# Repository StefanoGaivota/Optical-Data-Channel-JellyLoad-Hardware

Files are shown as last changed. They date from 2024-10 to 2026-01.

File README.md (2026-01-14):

Jelly Load is touted as one of the most inconvenient (but also most fun) ways of loading data into your 8 bit computer.<br>
The concept is the collaborative creation of Dave Curran (Tynemouth Software) and Rod Hull (The Future Was 8 bit).

Jelly-Load_Video-Excerpt

<br>
Data and clock signals are encoded into a video stream as a matrix of black or white areas.<br>
The receiving interface senses the optical channel bit state and converts the result into an 8 bit data word
for interpretation by the target computer upon receiving valid clock edge.

Take a look here:<br>
https://www.tfw8b.com/introducing-jelly-load/<br>
for a historical account.

The loader binaries for VIC20 can be found here:<br>
https://www.tfw8b.com/wp-content/uploads/2024/09/JellyLoad-VIC20-240908.zip<br>
(different ones depending upon your RAM configuration)

This repository is my own effort at creating a JellyLoad receive interface for Commodore computer user port.

It comprises two separate boards which connect to each other via a 14way IDC cable assembly along with associated opto-mechanical components.<br>
KiCAD source is available for schematic and PCB of each board.<br>
FreeCAD source is available for the mechanical elements (Optical Housing and Monitor Guide).<br>
Manufacturing data generated from these sources is detailed later in this document.<br><br>
<p><u><b>Printed Circuit Board parts</u></b></p><br>

* Optical Interface board:
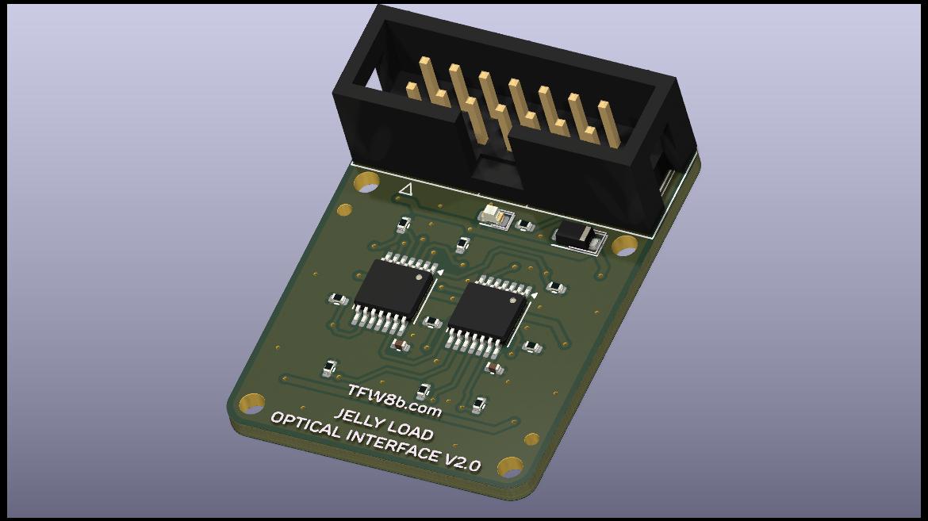
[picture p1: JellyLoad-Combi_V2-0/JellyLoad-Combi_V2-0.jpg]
Sensor-array-board

Phototransistors are arranged in the required matrix, photocurrent converted to voltage at input of Schmitt inverter. Inverter outputs are routed to 14 Way IDC.<br>
Clock signal is indicated by an LED for visual feedback of correct operation.<br>
Originally developed to use the OSRAM SFH3710 phototransistor, this seems to be superceded by the SFH3716 (as of December 2025).  Should be a drop-in replacement but YMMV.
<br><br>

* Target Interface board:
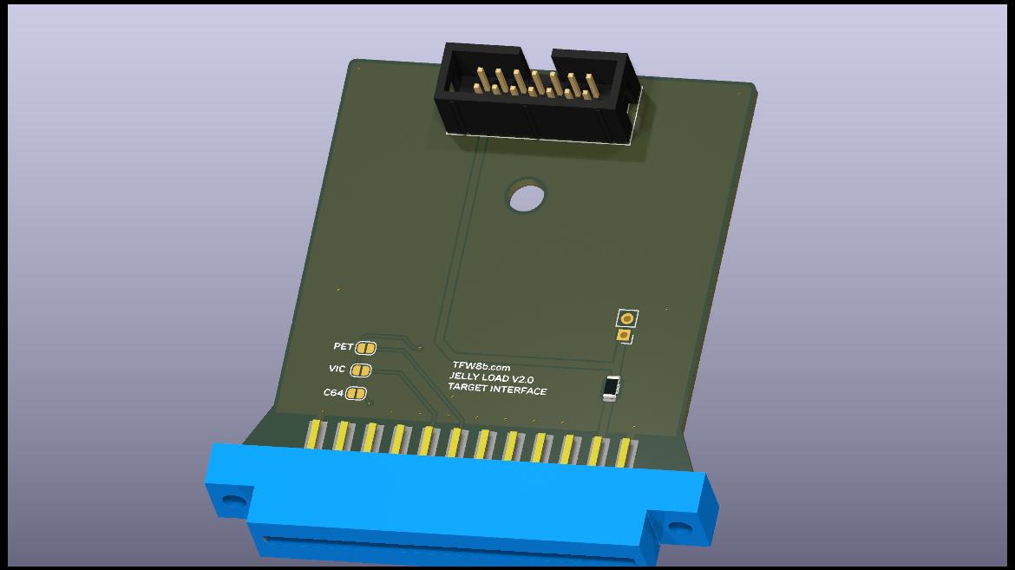
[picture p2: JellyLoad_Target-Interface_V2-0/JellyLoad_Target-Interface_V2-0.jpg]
Target-Interface-Board

Target interface connects the 14Way IDC pins and routes logic signals to target computer User Port connector.<br>
Solder blob config pads route the CLK signal to the user port pin required by the target computer.<br>
This differs between PET, VIC20 and C64. Blob your required option.<br>
Board profile is configured to fit inside a C64 cartridge case.<br>
Case mechanics are shown on layer User.Eco1.<br>
PDF of machining dimensions is made available for convenience.<br><br>
<br>
<p><u><b>Mechanical components</u></b></p><br>

* Optical Housing:
 
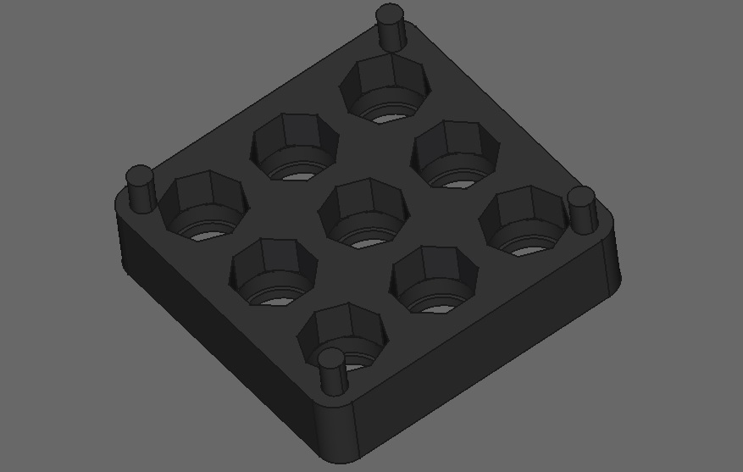
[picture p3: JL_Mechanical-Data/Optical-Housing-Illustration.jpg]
Optical-Housing


The Optical Interface board is fitted with this Optical Housing for the purpose of reducing ambient light interference and to help align with the optical channel.<br>
Optical aperture adaptors (glass spheres) are accommodated in this section to match the sensor aperture to the available width. A specification for suitable spheres is available in the mechanical data directory. Basically 6.0mm glass balls of good optical clarity.<br>
The graphical calculations shown here are based on a refractive index of 1.4.<br>

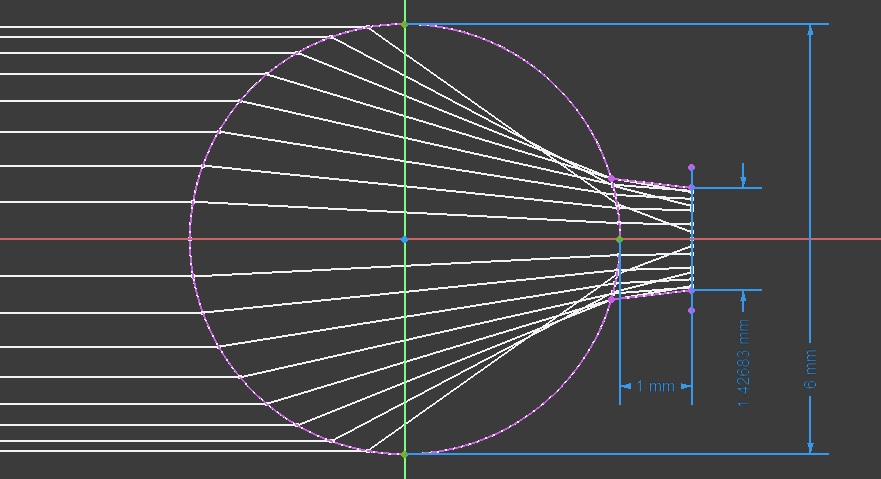
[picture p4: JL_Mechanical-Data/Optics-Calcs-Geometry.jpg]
Optics-Calculations

<br>
The sensor array will work adequately without the aperture adaptors but sensitivity will be reduced so you will need to use higher monitor brightness for reliable transmission. <br>
The housing can be secured to the sensor board with your adhesive of choice, (sticky tape, cyanoacrylate, blu-tack, toffee etc) or careful heat-staking of the retaining lugs.<br><br>

* Monitor Guide:

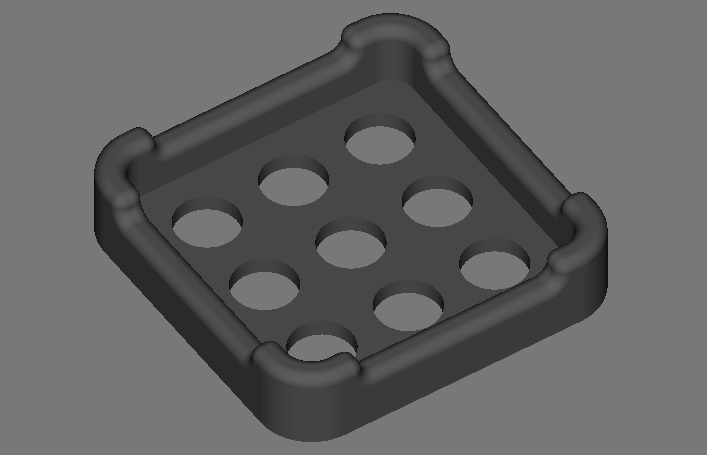
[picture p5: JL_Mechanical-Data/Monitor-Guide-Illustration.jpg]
Monitor-Guide


The Monitor Guide is attached to the receiving monitor screen, aligned with the appropriately scaled JellyLoad optical channel.<br><br>

<p><u><b>Manufacturing Data</u></b></p><br>

Manufacturing Data for production of Printed Circuit Boards and 3D printed mechanics is available in the "Manufacturing Data" folder.<br>

Bill-Of-Materials (BOM) with Digikey stock codes. BOM and pick/place files for use with JLC (A cheap and cheerful PCB Assembly company)<br>
Gerber+Drill zip for PCB manufacture.<br>

Assembly tooling holes are 1.152mm top-left and bottom right of layout. With JLC, specify "Tooling holes added by customer" at assembly stage.<br><br>

STL exports of Optical Housing and Monitor Guide can be used with most additive manufacturing processes.<br><br>

Once assembled, it should all look something like this:<br>

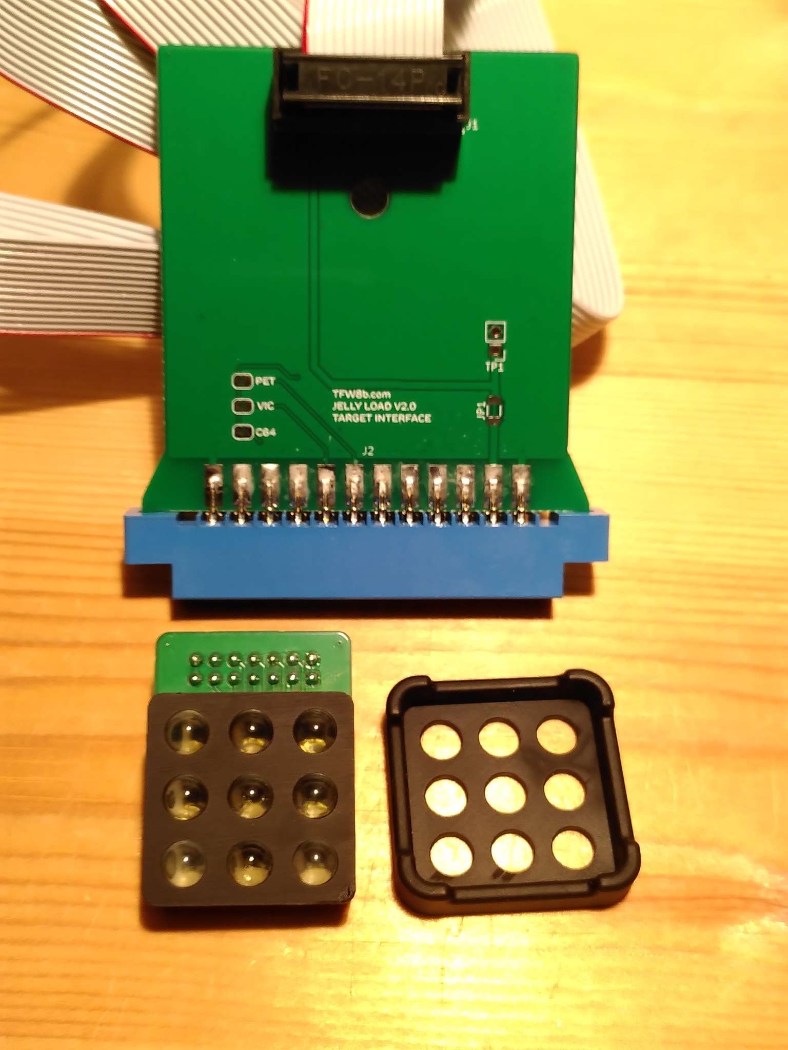
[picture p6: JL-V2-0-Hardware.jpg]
<br>

Then it's time to connect it up and try it out.<br>
Adjust monitor brightness to give reliable transition of CLOCK LED when presented with light or dark segments at the monitor.<br>
A usable Paint application is your friend here!
<br><br>
A selection of JellyLoad encoded videos can be found here:<br>
https://www.youtube.com/playlist?list=PLbE6E7xnjkkJwXpoj5DF8uXBsocBH2ZH-
<br><br>

Please feel free to get in touch if there's anything you'd like to ask about relating to this repository.<br>
I'm on:<br>
Bluesky  https://bsky.app/profile/stefanogaivota.bsky.social <br>
and <br>
Fedi     https://universeodon.com/@StefanoGaivota<br>
<br>
Best of luck!

</body>

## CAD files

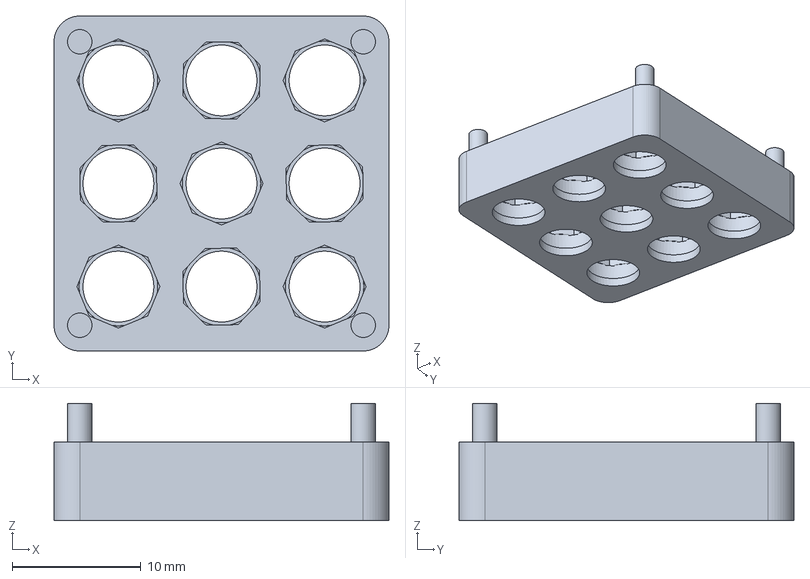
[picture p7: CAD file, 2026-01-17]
JL_Mechanical-Data/Optical-Housing.FCStd
26.0 x 26.0 x 9.10 mm

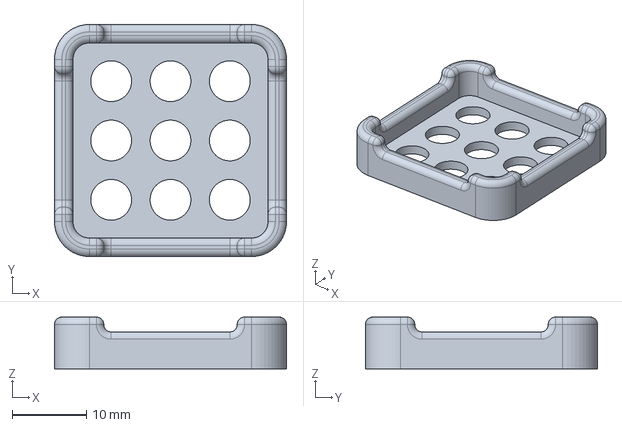
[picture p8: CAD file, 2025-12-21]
JL_Mechanical-Data/Monitor-Guide.FCStd
31.3 x 31.3 x 7.00 mm

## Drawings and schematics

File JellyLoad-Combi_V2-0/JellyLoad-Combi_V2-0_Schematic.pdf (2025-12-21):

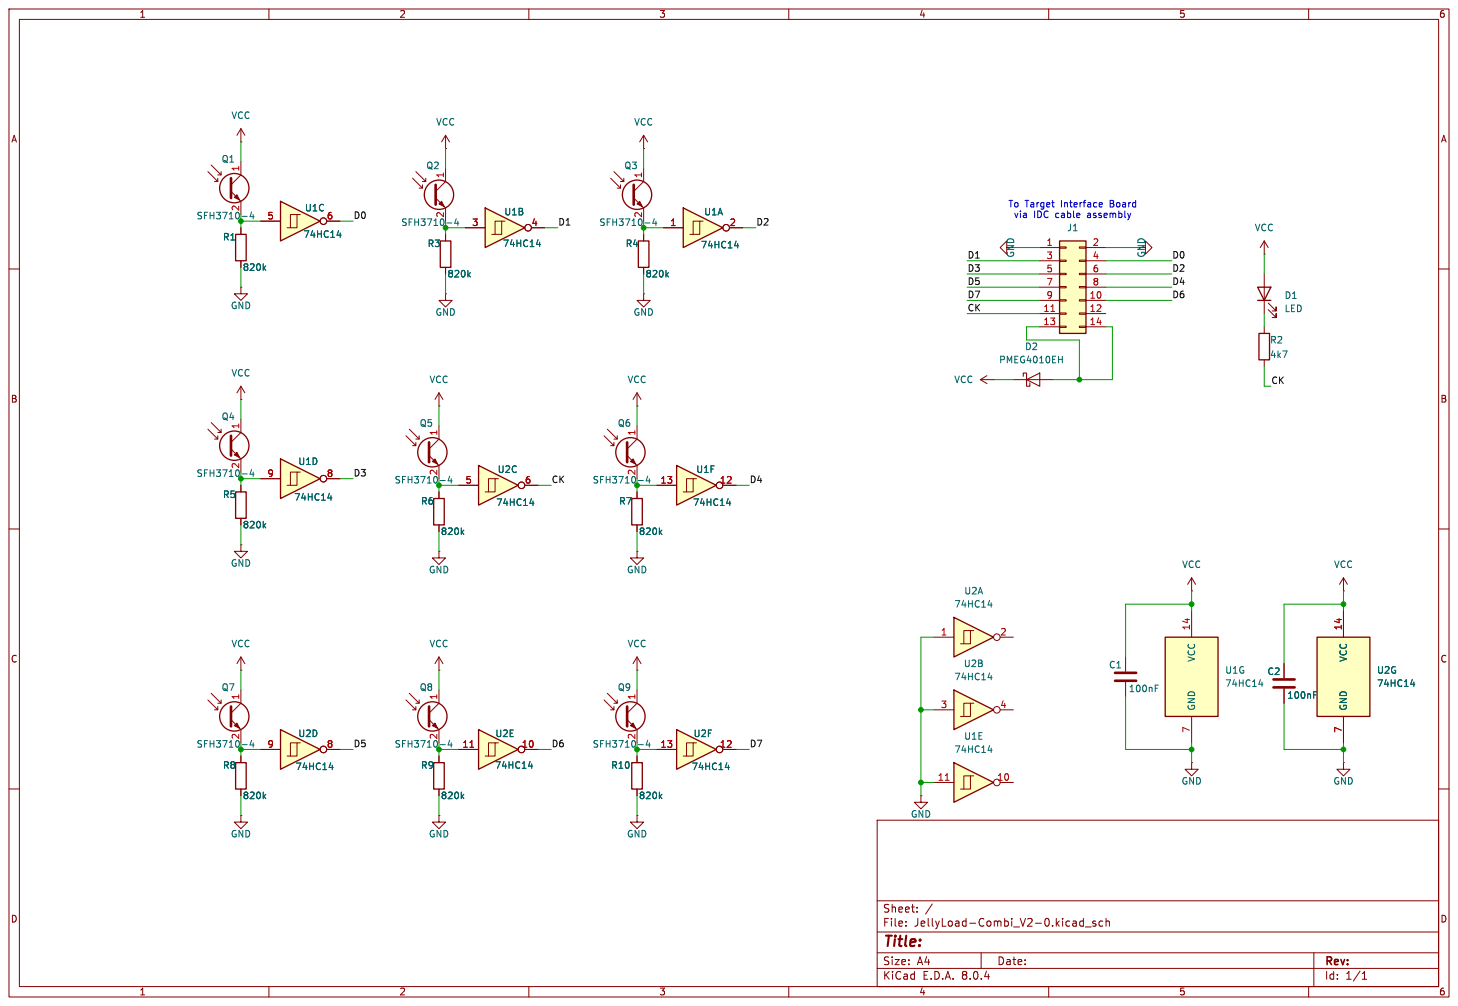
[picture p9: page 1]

Id: 1/1 Title: File: JellyLoad-Combi_V2-0.kicad_sch Sheet: / R5

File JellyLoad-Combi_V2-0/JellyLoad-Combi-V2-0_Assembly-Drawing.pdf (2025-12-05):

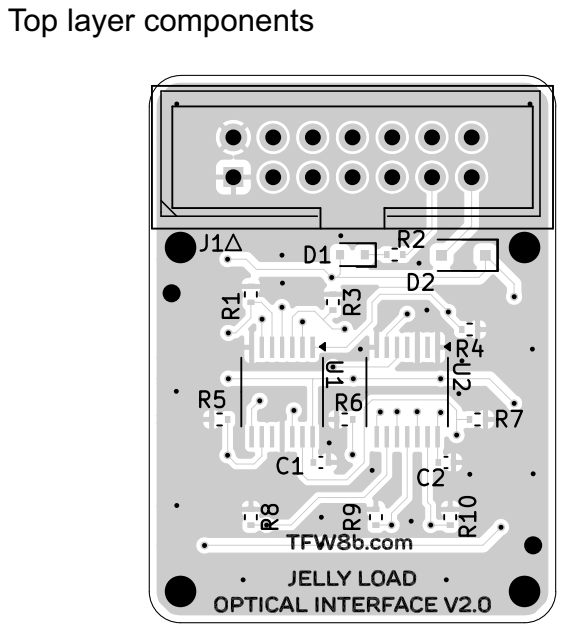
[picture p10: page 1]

Top layer components

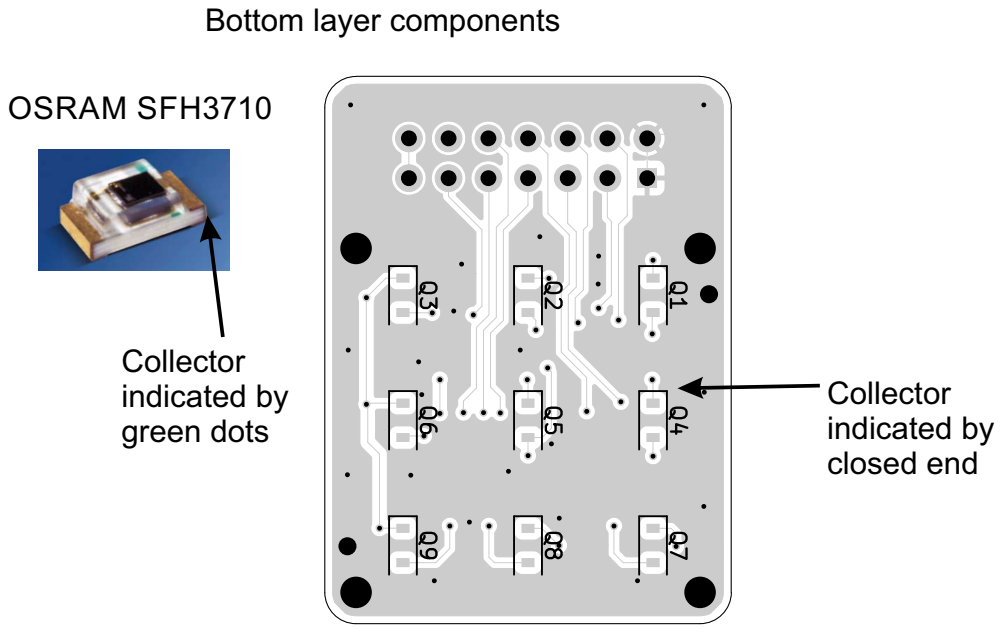
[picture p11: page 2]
OSRAM SFH3710; Collector indicated by green dots; Collector indicated by closed end

Bottom layer components

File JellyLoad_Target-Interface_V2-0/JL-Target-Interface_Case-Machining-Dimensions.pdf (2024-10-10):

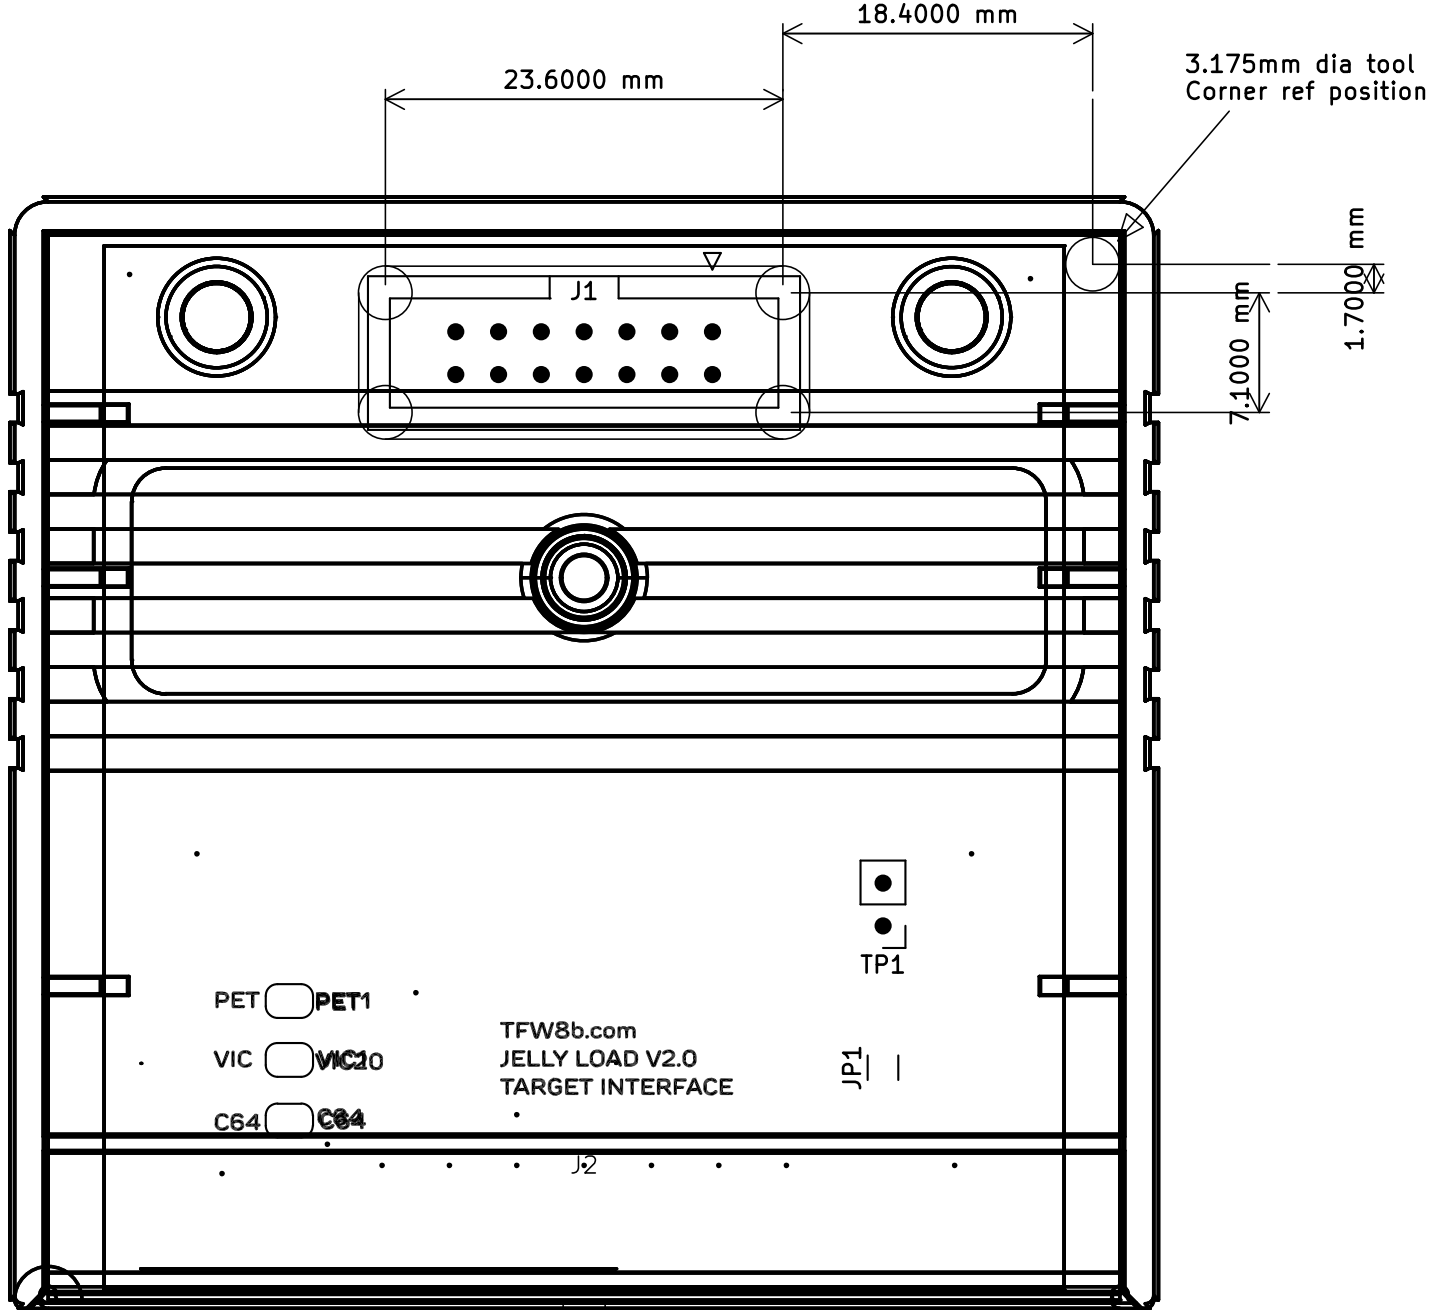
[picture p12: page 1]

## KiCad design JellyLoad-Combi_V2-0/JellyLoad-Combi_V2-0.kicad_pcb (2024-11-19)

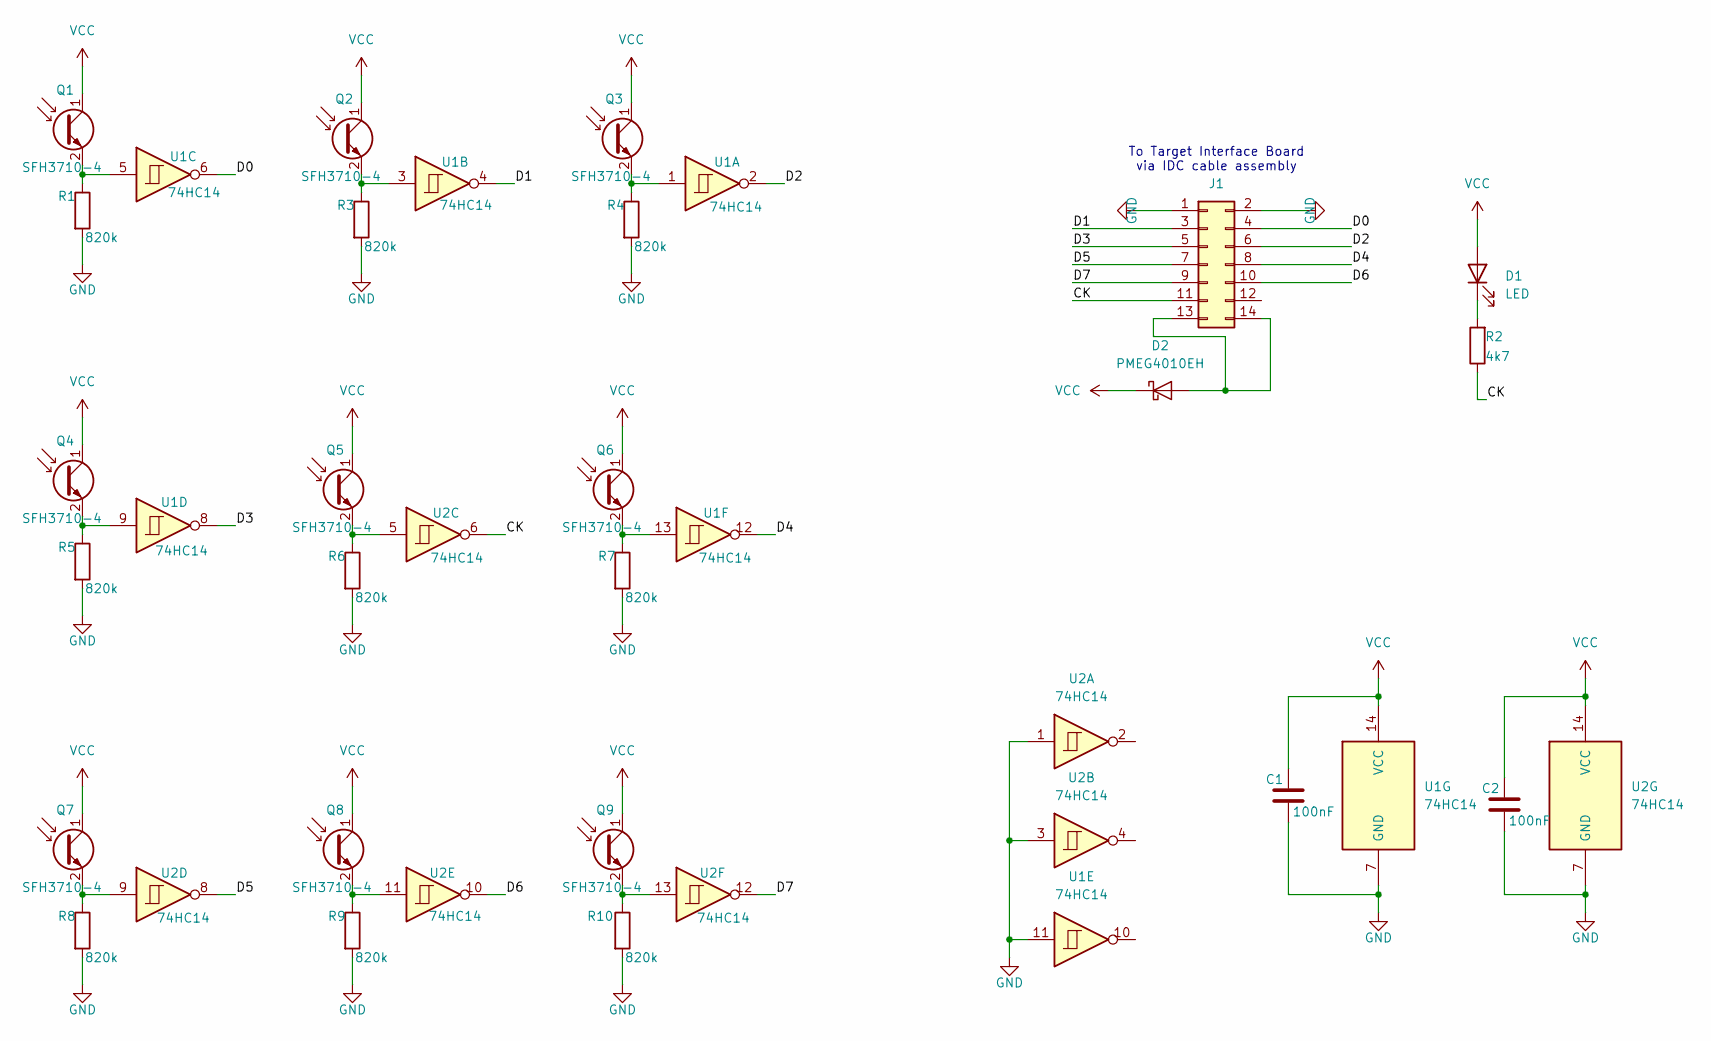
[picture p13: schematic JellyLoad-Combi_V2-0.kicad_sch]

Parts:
C1, C2: 100nF; C_0402_1005Metric
D1: LED; LED_0603_1608Metric; JLC PN C19273151
D2: PMEG4010EH; D_SOD-123F; JLC PN C2999987
J1: Conn_02x07_Odd_Even; IDC-Header_2x07_P2.54mm_Vertical; JLC PN C11215
Q1, Q2, Q3, Q4, Q5, Q6, Q7, Q8, Q9: SFH3710-4; Osram_SFH3710
R1, R3, R4, R5, R6, R7, R8, R9, R10: 820k; R_0402_1005Metric; JLC PN C144706
R2: 4k7; R_0402_1005Metric; JLC PN C138287
U1, U2: 74HC14; TSSOP-14_4.4x5mm_P0.65mm; JLC PN C6821

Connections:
/CK: J1.11, R2.1, U2.6
/D0: J1.4, U1.6
/D1: J1.3, U1.4
/D2: J1.6, U1.2
/D3: J1.5, U1.8
/D4: J1.8, U1.12
/D5: J1.7, U2.8
/D6: J1.10, U2.10
/D7: J1.9, U2.12
GND: C1.2, C2.2, J1.1, J1.2, R1.2, R3.2, R4.2, R5.2, R6.2, R7.2, R8.2, R9.2, R10.2, U1.7 (GND), U1.11, U2.1, U2.3, U2.7 (GND)
unnamed: D1.1 (K), R2.2
unnamed: D2.2 (A), J1.13, J1.14
unnamed: Q1.2 (E), R1.1, U1.5
unnamed: Q2.2 (E), R3.1, U1.3
unnamed: Q3.2 (E), R4.1, U1.1
unnamed: Q4.2 (E), R5.1, U1.9
unnamed: Q5.2 (E), R6.1, U2.5
unnamed: Q6.2 (E), R7.1, U1.13
unnamed: Q7.2 (E), R8.1, U2.9
unnamed: Q8.2 (E), R9.1, U2.11
unnamed: Q9.2 (E), R10.1, U2.13
VCC: C1.1, C2.1, D1.2 (A), D2.1 (K), Q1.1 (C), Q2.1 (C), Q3.1 (C), Q4.1 (C), Q5.1 (C), Q6.1 (C), Q7.1 (C), Q8.1 (C), Q9.1 (C), U1.14 (VCC), U2.14 (VCC)

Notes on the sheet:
To Target Interface Board via IDC cable assembly

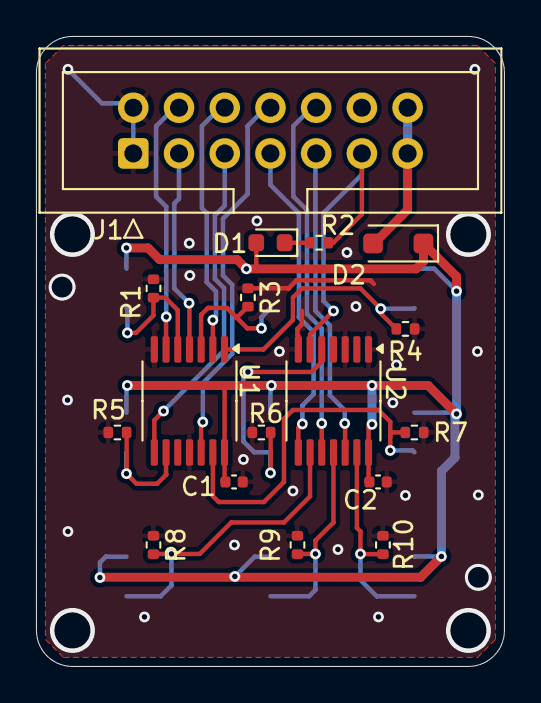
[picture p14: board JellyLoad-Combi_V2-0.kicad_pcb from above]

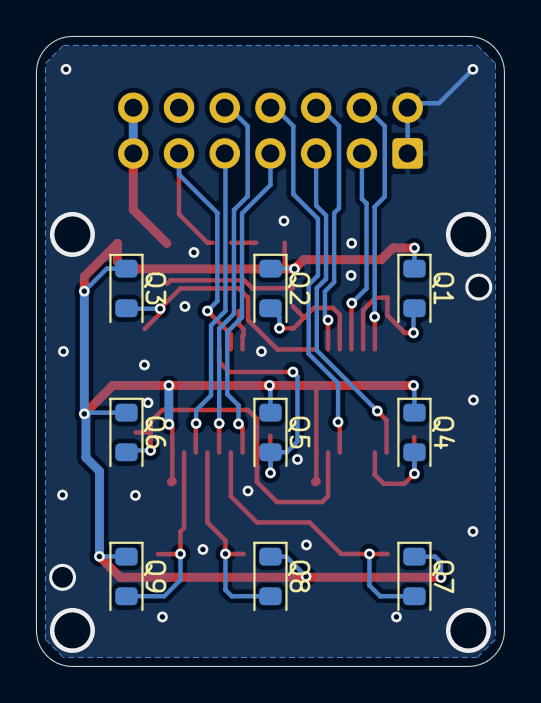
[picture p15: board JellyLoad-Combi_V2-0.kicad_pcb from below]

Board: 2 copper layers, 26.0 x 35.0 mm, 26 parts (9 on the bottom side), 22 nets.

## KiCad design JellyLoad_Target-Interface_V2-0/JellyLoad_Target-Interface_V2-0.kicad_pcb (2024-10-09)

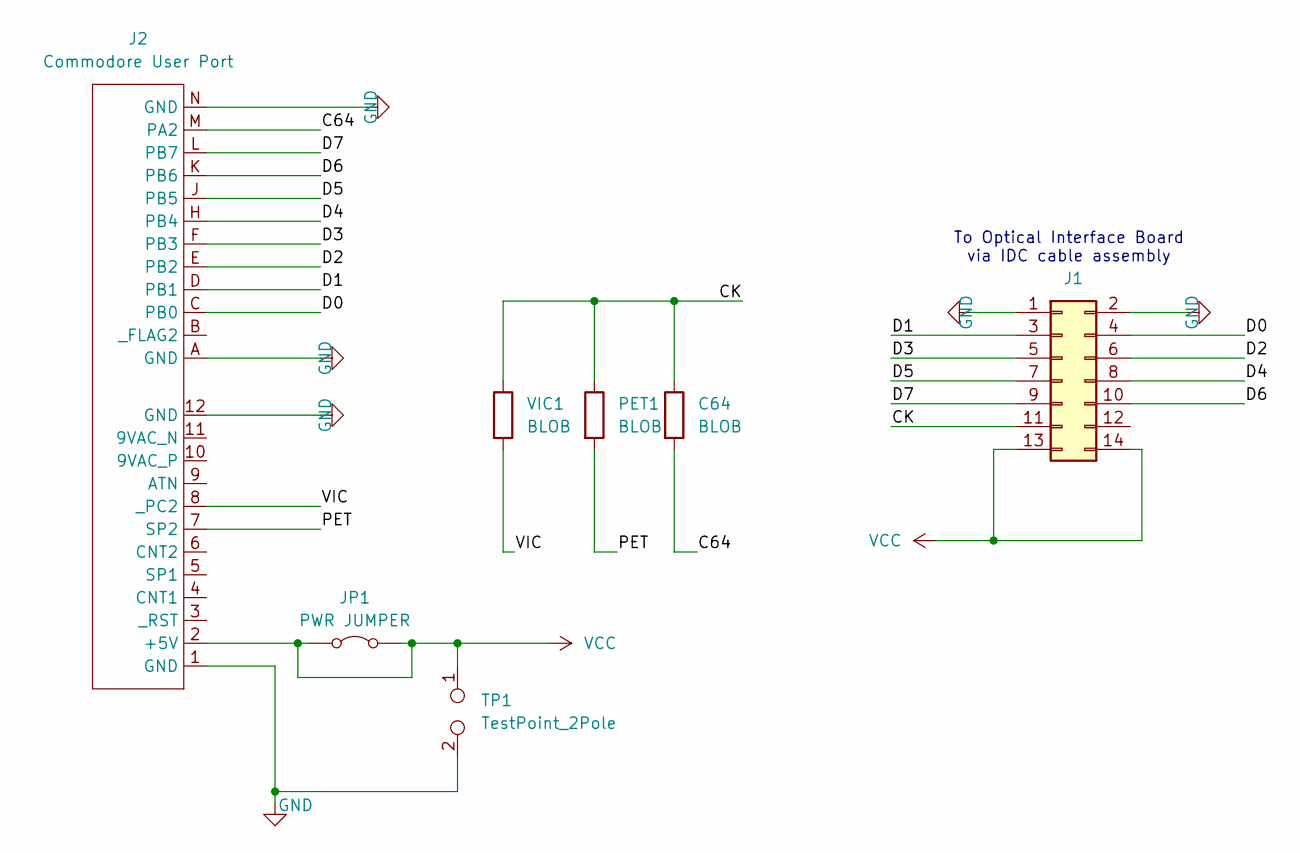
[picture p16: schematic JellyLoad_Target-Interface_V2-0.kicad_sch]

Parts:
C64: BLOB; SolderJumper-2_P1.3mm_Open_RoundedPad1.0x1.5mm
J1: Conn_02x07_Odd_Even; IDC-Header_2x07_P2.54mm_Vertical; JLC PN 571-1761681-5
J2: Commodore User Port; Commodore-UserPort-Connector; JLC PN 587-307-024 (Stupidly expensive, try Sw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
JP1: PWR JUMPER; R_1206_3216Metric
PET1: BLOB; SolderJumper-2_P1.3mm_Open_RoundedPad1.0x1.5mm
TP1: TestPoint_2Pole; PinHeader_1x02_P2.54mm_Vertical
VIC1: BLOB; SolderJumper-2_P1.3mm_Open_RoundedPad1.0x1.5mm

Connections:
/C64: C64.2, J2.M (PA2)
/CK: C64.1, J1.11, PET1.1, VIC1.1
/D0: J1.4, J2.C (PB0)
/D1: J1.3, J2.D (PB1)
/D2: J1.6, J2.E (PB2)
/D3: J1.5, J2.F (PB3)
/D4: J1.8, J2.H (PB4)
/D5: J1.7, J2.J (PB5)
/D6: J1.10, J2.K (PB6)
/D7: J1.9, J2.L (PB7)
/PET: J2.7 (SP2), PET1.2
/VIC: J2.8 (_PC2), VIC1.2
GND: J1.1, J1.2, J2.1 (GND), J2.12 (GND), J2.A (GND), J2.N (GND), TP1.2
VCC: J1.13, J1.14, J2.2 (+5V), JP1.1 (A), JP1.2 (B), TP1.1

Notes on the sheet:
To Optical Interface Board via IDC cable assembly

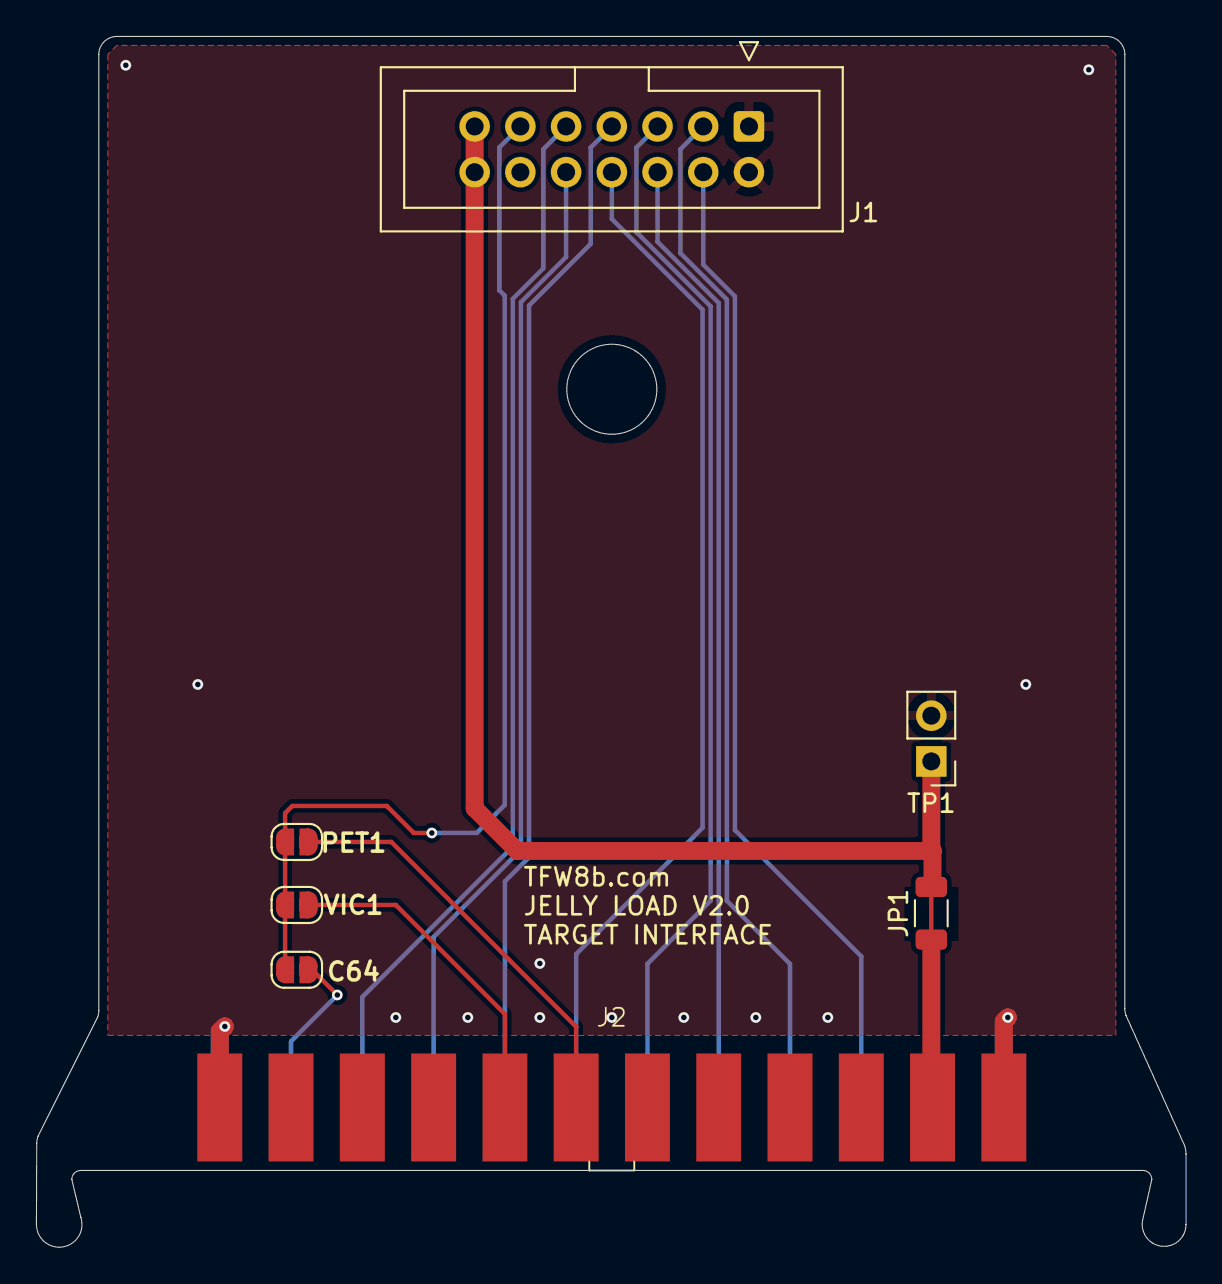
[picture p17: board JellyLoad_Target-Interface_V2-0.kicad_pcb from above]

Board: 2 copper layers, 63.9 x 67.3 mm, 7 parts (0 on the bottom side), 14 nets.

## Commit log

2024-10-09 KiCAD and manufacturing data uploaded
    LDR Sensor array, Signal Interface and Target Interface boards for JellyLoad system
    [JL_LDR-Sensor-Array.kicad_pcb, JL_LDR-Sensor-Array.kicad_sch, JL_Signal-Interface.kicad_pcb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]
2024-10-10 Cartridge case machining dimensions
    Dimensions of required cutting for cartridge case to create aperture for IDC connector.
    Based on using 3.175mm diameter cutting tool.
    Reference position is with tool touching top right internal corner as viewed from ABOVE as in the CAD view.
    NOTE: this will be MIRRORED in real life with the case upside down on the toolbed, so ref position shown in this diagram will be TOP LEFT on the toolbed.
    Easier for you to do the mental gymnastics than to reconfigure CAD and end up with something even more confusing.
2024-10-10 Updated Mfr data with better assembly drawing
2024-10-11 Added Mechanical Data for Optical Housing etc
    FreeCAD part design for Jelly Load Optical Housing and Monitor Guide. Export of STL for each part for use in additive manufacture process.
    [26x26mm_Monitor-Guide-Body.stl, 26x26mm_Optical-Housing-Body.stl, Monitor-Guide.FCStd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]
2024-10-15 Monitor Guide updated
    Monitor Guide crenellations to avoid clashing with IDC solder terminals. Upper faces filleted to smooth sharp edges
    [26x26mm_Monitor-Guide-Body.stl, Monitor-Guide.FCStd]
2024-10-16 Update to Optical Housing Illustration
    Optical Housing illustration updated to same display type as Monitor Guide piece
2024-10-24 Combi phototransistor sensor array
    Combined sensor array based on Osram SFH3710-4 phototransistor along with Schmitt inverters and shunts on the same board. This connects directly to the target interface. Optical characteristics will be adequately consistent using the "-4" suffix (high sensitivity bin) phototransistors. The numbers looked dodgy with the full spread of sensitivity values though. The -Z or no suffix option is cheaper, but there's a greater chance of the system not working due to sensitivity spread and you'll need to get more photrans to swap for any outliers.
    [JellyLoad-Combi_V2-0.kicad_pcb, JellyLoad-Combi_V2-0.kicad_sch, JellyLoad-Combi_V2-0_BOM.csv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]
2024-10-25 Update Optical Housing and Monitor Guide
    Optical Housing and Monitor Guide updated to accommodate and retain aperture matching optics for 2.0mm phototransistor.
    [26x26mm_Monitor-Guide-Body.stl, 26x26mm_Optical-Housing-Body.stl, Monitor-Guide.FCStd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]
2024-11-01 Monitor guide apertures widened
    Apertures widened to accommodate optical transformer spheres used with phototransistor variant
    [26x26mm_Monitor-Guide-Body.stl]
2024-11-02 Adjusted Optical Housing retaining lip
    Made the retaining lip thicker for simpler manufacture.
    [26x26mm_Optical-Housing-Body.stl, Optical-Housing.FCStd]
2024-11-15 Drill file and bottom copper update
    Corner mounting holes widened to 2.0mm for more robust mechanics. Added 2x tooling holes (1.152mm) for assembly process.
2024-11-15 Layout updates for manufacture process
    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
    [JellyLoad-Combi_V2-0.kicad_pcb]
2024-11-15 Thicker corner lugs, reduced vertical clearance
    Corner retaining lugs widened to 1.9mm for improved robustness. Clearance from aperture translator sphere to sensor reduced to 1.1mm to reduce rattle.
    [26x26mm_Optical-Housing-Body.stl, Optical-Housing.FCStd]
2024-11-15 Delete JL_LDR-Sensor-Array directory
    LDR sensor is too slow. Removing to simplify manufacture options.
    [JL_LDR-Sensor-Array.kicad_pcb, JL_LDR-Sensor-Array.kicad_sch]
2024-11-15 Delete JL_Signal-Interface directory
    Removing LDR option for simplicity. Signal interface board no longer necessary.
    [JL_Signal-Interface.kicad_pcb, JL_Signal-Interface.kicad_sch]
2024-11-15 Updated Drill and bottom copper
    Corner holes widened to 2.0mm, added 2x tooling holes (1.152mm) for assembly process.
2024-11-15 Combi board visualisation
    Eyecandy of combi board.
2024-11-15 Update README.md to reflect recent changes
    Project simplification. Narrative flow through to manufacturing processes.
2024-11-19 Admin updates to schematic and layout
    [JellyLoad-Combi_V2-0.kicad_pcb, JellyLoad-Combi_V2-0.kicad_sch]
2024-11-19 Added schematic PDF output and assembly drawing
2025-12-05 Manufacturing data all in one place
    Manfuacturing data (Gerbers, BOMs and component placements) for Sensor array board and Target Interface board
    STL (3D Print ) data for Monitor Guide and Optical Housing mechanics.
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2025-12-05 Updated assembly drawing
    Assembly drawing updated to better show orientation of SFH3710 photo-transistors
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2025-12-06 Delete Manufacturing-Data/JellyLoad-Combi-V2-0_Assembly-Drawing.pdf
    Assembly drawing for sensor array now in MDP
2025-12-06 Delete Manufacturing-Data/JellyLoad-Sensor-Board_MDP.zip
    Sensor array MDP updated. Simpler to delete previous version.
2025-12-07 Updated JLC Pick-and-Place data
    Pick and place data revised to show correct orientation and position of J1 connector.
2025-12-10 Sensor array MDP updated
    Sensor array MDP updated to include bottom layer components (phototransistors) and pick-place position data.
2025-12-21 Update to BOM
    LED part numbers changed to be RED LED consistently with JLC and Digikey
    [JellyLoad-Combi_V2-0.kicad_sch]
2025-12-21 Putting Mfr Data in one place
    Updated BOM and not duplicating manufacture data.
2025-12-21 Delete JellyLoad_Target-Interface_V2-0/Manufacturing-Data/JellyLoad_Target-Interface_V2-0_BOM.csv
    removing duplicate manufacture data
    [JellyLoad_Target-Interface_V2-0_BOM.csv]
2025-12-21 Mfr Tolerance update
    [Monitor-Guide.FCStd, Optical-Housing.FCStd]
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2025-12-30 Optical Housing updates
    Added retaining pips to sphere apertures. Consolidated constraints to named references.
    [Optical-Housing.FCStd]
2025-12-30 Updates to Optical Housing
    Optical Housing updated to include retaining pips in sphere apertures.
2026-01-02 Adjusted aperture and pips
    Widened aperture to allow easier installation of spheres. Retaining pip position adjusted to give allowance for material deformation.
    [Optical-Housing.FCStd]
2026-01-02 Optical housing aperture and pip adjustment
    Updated STL exports based on Optical Housing adjusted aperture and retaining pip positions.
2026-01-14 Thickened retaining pips
    Retaining pip thickness was below print process resolution. Made them thicker so they actually appear in the sliced print output. May need to experiment further with sizing and / or post-print proces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
    [Optical-Housing.FCStd]
2026-01-14 Updated STL export
    STL export updated to include thickened retaining pips in Optical Housing model.
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2026-01-17 Optical housing update
    Updated model to make sphere retention more easily manufactured using FDM processes. Using octagonal pocket for retention diameter then accommodation diameter thereafter. When sliced for FDM, this model shows retaining structures correctly.
    [Optical-Housing.FCStd]
2026-01-17 Updated STL model
    Optical housing update for FDM process.
